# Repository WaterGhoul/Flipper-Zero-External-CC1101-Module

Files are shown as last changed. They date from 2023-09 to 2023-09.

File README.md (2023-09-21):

# Flipper Zero External CC1101 Module
A universal module to add an external CC1101 modue to the Flipper Zero

# Configuration
This board is by default configured for an EByte CC1101 module, with the jumpers left as-is. These jumper pads are indicated by the surrounding dashed lined rectangle. 
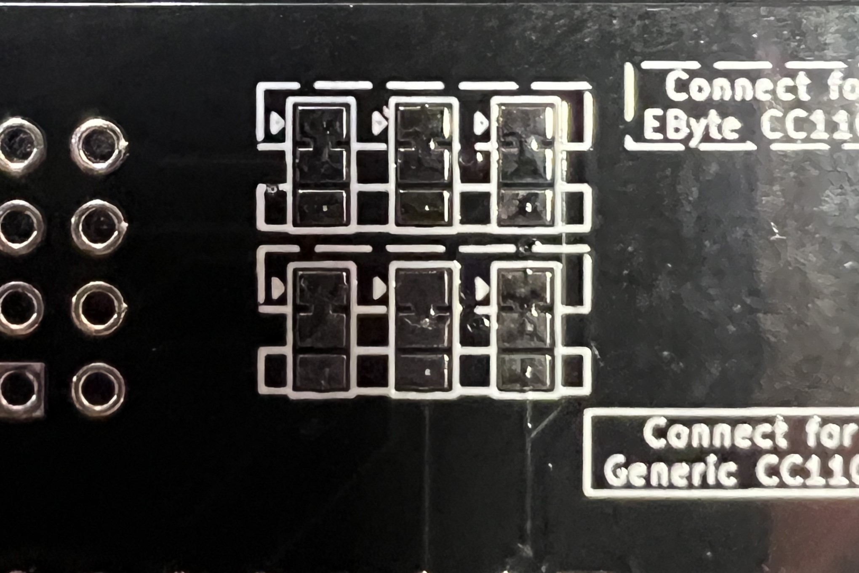
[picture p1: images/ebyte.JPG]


To congfigure the board for a generic CC1101 module, cut the default jumper traces with a knife and bridge the opposite jumper pads, indicated by the surounding solid lined rectangle.
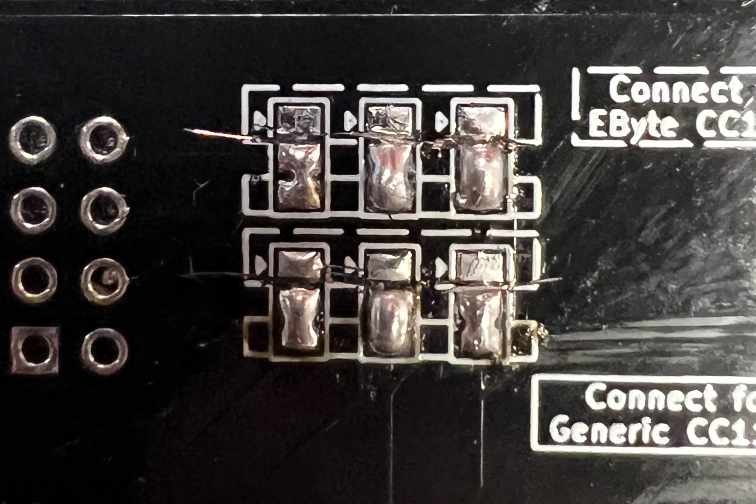
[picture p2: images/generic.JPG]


# Purchasing
You can purchase this and my other products on Tindie!



# Donate
Nothing is EVER expected for providing my designs, however if you wish to support my work, you may donate to these addresses.

**ETH** ``0x7C65625d6dac7DC351eEf3C0A21e9f0F4a3B537b``

**BTC** ``bc1q4rn3ceyk42349uuxt2m7mzw4kcewu0e5698fms``

**DOGE** ``DC1Q4ip8mLsAgvbLL4evxJQhaCE7QosFZ9``

**LTC** ``ltc1q33sg6eea2yqzdx85h38v7rpw7kzlgmqtn8m5nm``

# License
<br />This work is licensed under a <a rel="license" href="http://creativecommons.org/licenses/by-sa/4.0/">Creative Commons Attribution-ShareAlike 4.0 International License</a>.

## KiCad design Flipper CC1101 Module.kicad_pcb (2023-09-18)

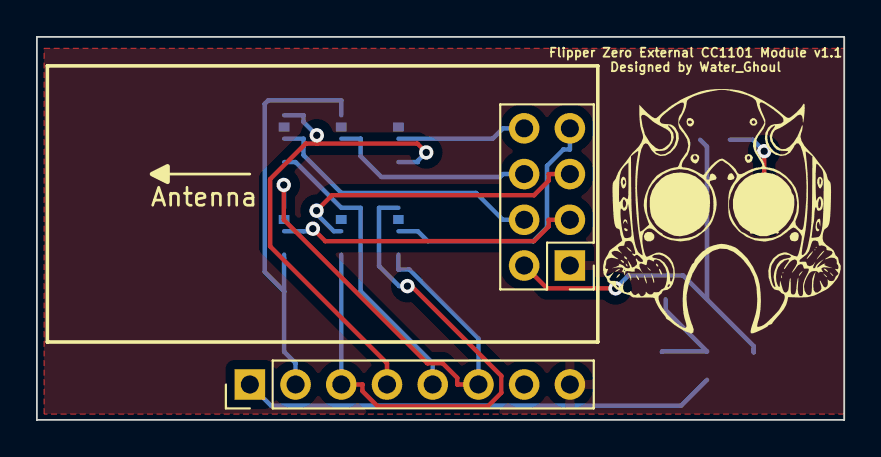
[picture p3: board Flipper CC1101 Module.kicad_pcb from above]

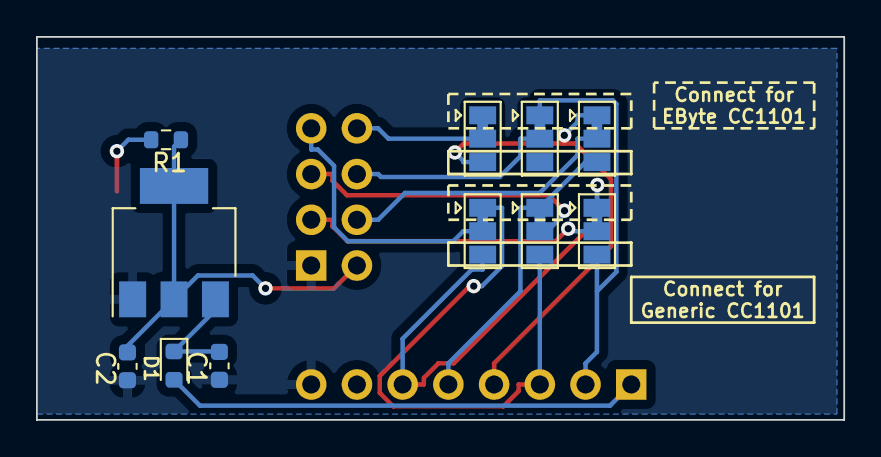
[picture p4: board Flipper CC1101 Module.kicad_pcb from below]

Board: 2 copper layers, 44.8 x 21.3 mm, 14 parts (11 on the bottom side), 16 nets.

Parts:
C1: 10uF; C_0603_1608Metric
C2: 100uF; C_0603_1608Metric
D1: 1N4001; D_0603_1608Metric
D2: LED; LED_0603_1608Metric
J1: EByte CC1101; PinHeader_2x04_P2.54mm_Vertical
J3: Conn_01x08; PinHeader_1x08_P2.54mm_Vertical
JP1, JP2, JP3, JP4, JP5, JP6: SolderJumper_3_Bridged12; SolderJumper-3_P1.3mm_Bridged12_Pad1.0x1.5mm
R1: 1k; R_0603_1608Metric
U1: AMS1117CD-3.3; SOT-223-3_TabPin2

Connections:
+3V3: C2.1, J1.2, R1.1, U1.2 (VO)
+5V: D1.2 (A), J3.1
CS: J3.4, JP2.1 (A), JP5.3 (B)
GD0: J3.6, JP1.1 (A), JP6.3 (B)
GND: C1.2, C2.2, D2.1 (K), J1.1, J3.8, U1.1 (GND)
MISO: J3.3, JP3.3 (B), JP6.1 (A)
MOSI: J3.2, JP1.3 (B), JP4.1 (A)
unnamed: C1.1, D1.1 (K), U1.3 (VI)
unnamed: D2.2 (A), R1.2
PIN3: J1.3, JP1.2 (C)
PIN4: J1.4, JP2.2 (C)
PIN5: J1.5, JP3.2 (C)
PIN6: J1.6, JP4.2 (C)
PIN7: J1.7, JP6.2 (C)
PIN8: J1.8, JP5.2 (C)
SCK: J3.5, JP2.3 (B), JP3.1 (A)

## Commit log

2023-09-18 Add files via upload
    Added KiCAD source files
    [Flipper CC1101 Module.kicad_pcb, Flipper CC1101 Module.kicad_sch]
2023-09-18 Add KiCAD Project file
2023-09-21 Added Images
    Added images showing the default EByte module configuration of the jumpers and the optional cut and soldered configuration of the jumpers for a generic module.
